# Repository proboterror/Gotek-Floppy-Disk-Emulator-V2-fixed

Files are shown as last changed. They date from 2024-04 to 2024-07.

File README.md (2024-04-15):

Fixed PCB from original [Gotek-Floppy-Disk-Emulator-V2](https://github.com/RichardRozehnal/Gotek-Floppy-Disk-Emulator-V2):
* Add PCB edge cut for IDC 34-pin cable keying
* Change Buzzer type from Active to Passive (single click on drive motor step)
* Change "Buzzer_12x9.5RM7.6" footprint to "Buzzer_12x9.5RM6.5"

# Gotek Floppy Disk Emulator V2

Gotek Floppy Disk Emulator V2

Emulátor disketové mechaniky starých počítačů a různých zařízení. Software se do počítače nahrává z obrazu originálního disku (např. ADF pro Amigu), který je uložen na USB flash disku. Tato verze hardwaru využívá firmware [FlashFloppy](https://github.com/keirf/FlashFloppy/wiki), který přidává spoustu nových funkcí a vylepšení oproti standardnímu Goteku. Na uvedém odkazu tvůrce, najdete detailní popisy všech funkcí a nastavení a také nejnovější firmware.

## Seznam součástek

| **Ref** | **Qnty** | **Value** | **Cmp name** |
| --- | :---: | --- | --- |
| BZ1, | 1 | 5V Passive Buzzer 12mm | Buzzer |
| C1, C2, C4, C7, C8, C9, C10, C12, | 8 | 100nF | C |
| C3, C11, | 2 | 10uF | C |
| C5, C6, | 2 | 22pF | C |
| C13, | 1 | 4.7uF/16V | CP |
| D1, | 1 | LED Green | LED |
| D2, | 1 | 1N4148 | D |
| J1, | 1 | Power Connector | Conn\_01x04 |
| J2, | 1 | OLED Display 0.91" Module | OLED\_Display\_0.91"\_Module |
| J3, | 1 | USB\_A | USB\_A |
| J5, | 1 | Programming Connector | Conn\_02x05\_Odd\_Even |
| J6, | 1 | Floppy Data Connector | Conn\_02x17\_Odd\_Even |
| Q1, | 1 | MMBT2222 | Q\_NPN\_BEC |
| Q2, Q3, Q4, Q5, Q6, Q7, | 6 | BSS123 | BSS123 |
| R1, | 1 | 4K7 | R |
| R2, R3, R7, R8, R9, R10, R11, R12, R13, R14, R15, R16, R17, R18, R19, R20, R21, R22, R23, R24, R25, R26, | 22 | 1K | R |
| R4, R27 | 2 | 10K | R |
| R5, R6, | 2 | 22R | R |
| SW1, | 1 | KY040 Rotary Encoder Module | KY040\_Rotary\_Encoder\_Module |
| SW2, | 1 | DIP Switch | DIP\_Switch |
| U1, | 1 | AMS1117-3.3 | AMS1117-3.3 |
| U2, | 1 | STM32F105RBTx | STM32F105RBTx |
| U3, | 1 | STMPS2141 | STMPS2141 |
| U4, | 1 | 74HCT04 | 74HCT04 |
| Y1, | 1 | 8MHz | Crystal |

## Oživení

### Programování mikrokontroléru pomocí ST-Link V2

1. stáhněte si a nainstalujte flashovací program STM32-ST-Link Utility na webu [st.com](https://www.st.com/en/development-tools/stsw-link004.html).
2. propojte ST-Link V2 a Gotek V2 vývody SWCLK, SWDIO, GND a +3.3V
3. připojte ST-Link V2 k PC a spusťte flashovací program
4. připojte se na MCU přes menu Target/Connect
5. přes menu File/Open File vyberte soubor FF_Gotek-v3.20.hex (nebo jiný, který chcete nahrát do MCU)
6. spusťte flashování přes menu Target/Program & Verify a Start

### Nastavení DIP přepínače SW2

Pro Amigu, Atari ST a další počítače je nastavení:

| **sig** | **zap/vyp** | **funkce** |
| :-----: | :---: | --- |
| DC1 | OFF | |
| DC2 | ON | |
| J5 | OFF | |
| JC | OFF | |
| JB | ON | zapnutí/vypnutí emulace zvuku mechaniky |
| S0 | ON | |
| S1 | OFF | |

### Příprava USB flash disku a základní operace

1. USB flash disk naformátujte na FAT32 a nahrajte na něj obrazy disků, které budete chtít spouštět, např. ADF pro Amigu
2. připojte Gotek V2 s vloženým USB flash diskem k Amize (místo interního floppy disku), napájecí konektor je dobré před zapojením změřit, abyste do Goteku V2 nepustili 12V místo 5V, kvůli obrácení konektoru!
3. zapněte Amigu, na displeji se zobrazí první z podporovaných souborů, které jste nahráli a rotačním enkodérem mezi nima vybíráte
4. když najedete na soubor a počkáte 2s, tak se automaticky spustí (vloží do floppy mechaniky). Toto je možné v nastavení změnit, aby se automaticky nespouštěl. Potom bude pro vložení do mechaniky nutné stisknout rotační enkodér.
5. pokud chcete změnit orientaci posuvu v souborech (otáčení enkodéru doprava/doleva posouvat soubory nahoru/dolů), je to možné změnit v nastavení.
6. pokud se výběr souborů posune o jednu položku až při dvou nebo čtyřech krocích otočení enkodérem, je možné toto také upravit v nastavení

### Nastavení firmware

1. Gotek V2 funguje s defaultním nastavením i bez konfiguračního souboru
2. pokud však chcete určitou konfiguci změnit, vytvořte na USB flash disku adresář FF a do něj nahrajte konfigurační soubor FF.CFG
3. zrušení automatického spouštění souboru: autoselect-file-secs = 0
4. zrušení automatického vybrání adresáře: autoselect-folder-secs = 0
5. změna orientace posuvu v souborech: rotary = reverse
6. změna kroků enkodéru: rotary = half
7. je možné vybrat i více nastavení najednou, např.: rotary = reverse,half

## Další fotky (vzorky, úprava na BOT straně již není potřeba)

Gotek_V2_PCB_Top
Gotek_V2_PCB_Bot
Gotek_V2_PCB_Bot_osazeny

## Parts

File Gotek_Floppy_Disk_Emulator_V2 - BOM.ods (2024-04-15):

Gotek Floppy Disk Emulator V2 – BOM
Ref | Qnty | Value | Cmp name | Footprint
BZ1, | 1 | 5V Passive Buzzer 12mm | Buzzer | Buzzer_12x9.5RM6.5
C1, C2, C4, C7, C8, C9, C10, C12, | 8 | 100nF | C | C_1206_3216Metric
C3, C11, | 2 | 10uF | C | C_1206_3216Metric
C5, C6, | 2 | 22pF | C | C_1206_3216Metric
C13, | 1 | 4.7uF/16V | CP | CP_EIA-3216-18_Kemet-A
D1, | 1 | LED Green | LED | LED_D3.0mm
D2, | 1 | 1N4148 | D | D_MiniMELF
J1, | 1 | Power Connector | Conn_01x04 | PinHeader_1x04_P2.54mm_Horizontal
J2, | 1 | OLED Display 0.91" Module | OLED_Display_0.91"_Module | OLED_Display_0.91_Module
J3, | 1 | USB_A | USB_A | USB_A_Stewart_SS-52100-001_Horizontal
J5, | 1 | Programming Connector | Conn_02x05_Odd_Even | PinHeader_2x05_P2.54mm_Vertical
J6, | 1 | Floppy Data Connector | Conn_02x17_Odd_Even | PinHeader_2x17_P2.54mm_Horizontal
Q1, | 1 | MMBT2222 | Q_NPN_BEC | SOT-23
Q2, Q3, Q4, Q5, Q6, Q7, | 6 | BSS123 | BSS123 | SOT-23
R1, | 1 | 4K7 | R | R_1206_3216Metric
R2, R3, R7, R8, R9, R10, R11, R12, R13, R14, R15, R16, R17, R18, R19, R20, R21, R22, R23, R24, R25, R26, | 22 | 1K | R | R_1206_3216Metric
R4, R27 | 2 | 10K | R | R_1206_3216Metric
R5, R6, | 2 | 22R | R | R_1206_3216Metric
SW1, | 1 | KY040 Rotary Encoder Module | KY040_Rotary_Encoder_Module | PinHeader_1x05_P2.54mm_Vertical
SW2, | 1 | DIP Switch | DIP_Switch | SW_DIP_SPSTx08_Slide_6.7x21.88mm_W8.61mm_P2.54mm_LowProfile
U1, | 1 | AMS1117-3.3 | AMS1117-3.3 | SOT-223-3_TabPin2
U2, | 1 | STM32F105RBTx | STM32F105RBTx | LQFP-64_10x10mm_P0.5mm
U3, | 1 | STMPS2141 | STMPS2141 | SOT-23-5
U4, | 1 | 74HCT04 | 74HCT04 | SOIC-14_3.9x8.7mm_P1.27mm
Y1, | 1 | 8MHz | Crystal | Crystal_HC49-4H_Vertical

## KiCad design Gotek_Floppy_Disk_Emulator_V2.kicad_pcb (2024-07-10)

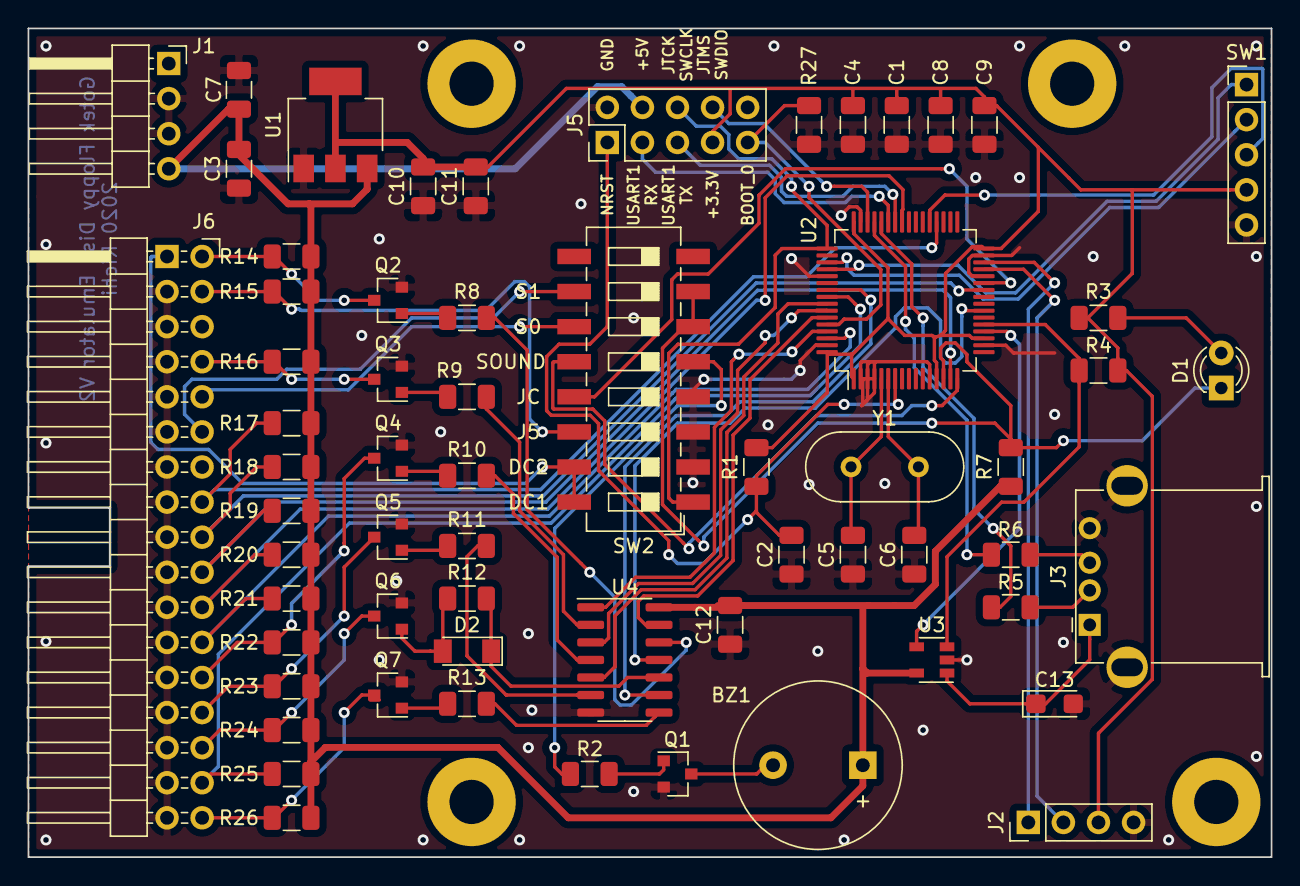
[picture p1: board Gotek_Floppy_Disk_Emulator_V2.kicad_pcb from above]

Board: 2 copper layers, 90.0 x 60.0 mm, 62 parts (0 on the bottom side), 64 nets.

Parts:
BZ1: 5V Passive Buzzer 12mm; Buzzer_12x9.5RM6.5
C1, C2, C4, C7, C8, C9, C10, C12: 100nF; C_1206_3216Metric
C3, C11: 10uF; C_1206_3216Metric
C5, C6: 22pF; C_1206_3216Metric
C13: 4.7uF/16V; CP_EIA-3216-18_Kemet-A
D1: LED Green; LED_D3.0mm
D2: 1N4148; D_MiniMELF
J1: Power Connector; PinHeader_1x04_P2.54mm_Horizontal
J2: OLED Display 0.91" Module; OLED_Display_0.91_Module
J3: USB_A; USB_A_Stewart_SS-52100-001_Horizontal
J5: Programming Connector; PinHeader_2x05_P2.54mm_Vertical
J6: Floppy Data Connector; PinHeader_2x17_P2.54mm_Horizontal
Q1: MMBT2222; SOT-23
Q2, Q3, Q4, Q5, Q6, Q7: BSS123; SOT-23
R1: 4K7; R_1206_3216Metric
R2, R3, R7, R8, R9, R10, R11, R12, R13, R14, R15, R16, R17, R18, R19, R20, R21, R22, R23, R24, R25, R26: 1K; R_1206_3216Metric
R4, R27: 10K; R_1206_3216Metric
R5, R6: 22R; R_1206_3216Metric
SW1: KY040 Rotary Encoder Module; PinHeader_1x05_P2.54mm_Vertical
SW2: DIP Switch; SW_DIP_SPSTx08_Slide_6.7x21.88mm_W8.61mm_P2.54mm_LowProfile
U1: AMS1117-3.3; SOT-223-3_TabPin2
U2: STM32F105RBTx; LQFP-64_10x10mm_P0.5mm
U3: STMPS2141; SOT-23-5
U4: 74HCT04; SOIC-14_3.9x8.7mm_P1.27mm
Y1: 8MHz; Crystal_HC49-4H_Vertical

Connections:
+3V3: C1.1, C4.1, C8.1, C9.1, C10.1, C11.1, J2.3, J5.7, R1.1, R3.2, R4.2, SW1.4, U1.2, U2.1, U2.13, U2.19, U2.32, U2.48, U2.64
+5V: BZ1.1, C3.1, C7.1, C12.1, J1.4, J5.4, R7.2, R14.2, R15.2, R16.2, R17.2, R18.2, R19.2, R20.2, R21.2, R22.2, R23.2, R24.2, R25.2, R26.2, U1.3, U3.5, U4.14
BOOT_0: J5.9, R27.1, U2.60
FPI5V_DIRn: J6.18, R18.1, U2.26
FPI5V_DSELn: D1.1, R7.1, SW2.6, SW2.7, U2.14
FPI5V_SIDEn: J6.32, R25.1, U2.56
FPI5V_STEPn: J6.20, R19.1, U2.15
FPI5V_WDATAn: J6.22, R20.1, U2.41
FPI5V_WGATEn: J6.24, R21.1, U2.62
FPO3V_DSKCHGn: U2.59, U4.13
FPO3V_INDEXn: U2.61, U4.1
FPO3V_RDDATAn: U2.23, U4.11
FPO3V_READYn: U2.55, U4.9
FPO3V_TRK00n: U2.58, U4.3
FPO3V_WPTn: U2.57, U4.5
GNDD: C1.2, C2.2, C3.2, C4.2, C5.2, C6.2, C7.2, C8.2, C9.2, C10.2, C11.2, C12.2, C13.2, J1.2, J1.3, J2.4, J3.4, J3.5, J5.2, J6.3, J6.5, J6.7, J6.9, J6.11, J6.13, J6.15, J6.17, J6.19, J6.21, J6.23, J6.25, J6.27, J6.29, J6.31, J6.33, Q1.2, Q2.2, Q3.2, Q4.2, Q5.2, Q6.2, Q7.2, R27.2, SW1.5, SW2.2, SW2.3, SW2.4, U1.1, U2.2, U2.3, U2.4, U2.12, U2.18, U2.28, U2.31, U2.47, U2.53, U2.63, U3.2, U4.7
JTCK-SWCLK: J5.6, SW2.1, U2.49
JTMS-SWDIO: J5.8, U2.46
JUMPER_JB: SW2.12, U2.16
JUMPER_JC: SW2.13, U2.27
MOTOR_SIGNAL: J6.16, R17.1, U2.36
NRST: C2.1, J5.1, R1.2, U2.7
unnamed: BZ1.2, Q1.3
unnamed: C5.1, U2.5, Y1.1
unnamed: C6.1, U2.6, Y1.2
unnamed: C13.1, J3.1, U3.1
unnamed: D1.2, R3.1
unnamed: D2.1, R12.1, U4.10
unnamed: D2.2, Q6.1, R12.2
unnamed: J2.1, U2.30
unnamed: J2.2, U2.29
unnamed: J3.2, R5.2
unnamed: J3.3, R6.2
unnamed: J6.1, SW2.15, SW2.16
unnamed: J6.2, Q2.3, R14.1
unnamed: J6.4, R15.1, SW2.14
unnamed: J6.8, Q3.3, R16.1
unnamed: J6.10, SW2.11
unnamed: J6.12, SW2.10
unnamed: J6.26, Q4.3, R22.1
unnamed: J6.28, Q5.3, R23.1
unnamed: J6.30, Q6.3, R24.1
unnamed: J6.34, Q7.3, R26.1
unnamed: Q1.1, R2.2
unnamed: Q2.1, R8.2
unnamed: Q3.1, R9.2
unnamed: Q4.1, R10.2
unnamed: Q5.1, R11.2
unnamed: Q7.1, R13.2
unnamed: R4.1, U2.21, U3.3
unnamed: R5.1, U2.44
unnamed: R6.1, U2.45
unnamed: R8.1, U4.12
unnamed: R9.1, U4.2
unnamed: R10.1, U4.4
unnamed: R11.1, U4.6
unnamed: R13.1, U4.8
unnamed: SW1.1, U2.52
unnamed: SW1.2, U2.51
unnamed: SW1.3, U2.37
unnamed: U2.20, U3.4
SOUND: R2.1, SW2.5
USART1_RX: J5.3, U2.43
USART1_TX: J5.5, U2.42

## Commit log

2024-04-15 Fixed PCB from original https://github.com/RichardRozehnal/Gotek-Floppy-Disk-Emulator-V2: * Add PCB edge cut for IDC 34-pin cable keying * Change Buzzer type from Active to Passive (single click on d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
    Update BoM.
    Add Buzzer_12x9.5RM6.5 footprint and 3D model.
    Delete unused files.
    [Gotek_Floppy_Disk_Emulator_V2 - BOM.ods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]
2024-07-10 USB connector oval mounting holes.
    [Gotek_Floppy_Disk_Emulator_V2-B_Cu.gbr, Gotek_Floppy_Disk_Emulator_V2-B_Mask.gbr, Gotek_Floppy_Disk_Emulator_V2-B_SilkS.gbr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]
